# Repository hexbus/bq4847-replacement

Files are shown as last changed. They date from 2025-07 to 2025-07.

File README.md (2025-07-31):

# BQ4847 Replacement Module

**Drop-in replacement for the BQ4847Y DIP RTC chip using the BQ4802Y for 5V legacy systems.**  
Maintains full functionality with modern, readily available components.

---

## Table of Contents

- [Overview](#overview)
- [Photos](#photos)
  - [Assembled Replacement Module](#assembled-replacement-module)
  - [BQ4802Y Module (Modern)](#bq4802y-module-modern)
  - [BQ4847Y Chip (Original)](#bq4847y-chip-original)
- [Project Status](#project-status)
- [Bill of Materials (BOM)](#bill-of-materials-bom)
- [Installation Instructions](#installation-instructions)
  - [TI-99/4A IDE Card](#bq4852-ti99-ide-card)
- [License](#license)
- [Author](#author)

---

## Overview

Many legacy computer systems used the BQ4847 real-time clock (RTC) chip—an integrated lithium coin-cell battery-backed chip with a typical 10-year lifespan. Today, most of thee original chips are well beyond their intended service life.

This project provides a drop-in replacement using the newer BQ4802Y clock chip. It includes support for a replaceable 3V CR2032 battery via an XH 2-pin connector. Note that while the original BQ4847 supported an external 512K SRAM module, this project does **not** include that memory. However, the BQ4802Y can still manage external SRAM if present.

This design was created specifically for use in the [TI-99/4A IDE Card](http://www.mainbyte.com/ti99/ide_card/ide_card.html), which has a dedicated footprint for the BQ4847.

---

## Photos

### Assembled Replacement Module  
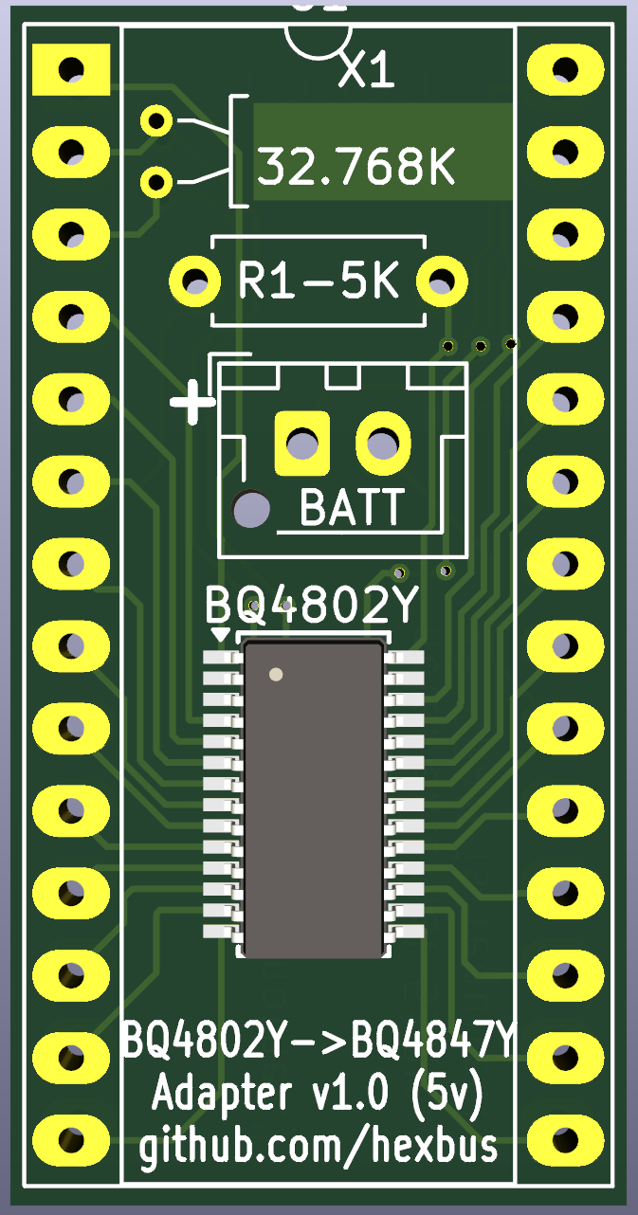
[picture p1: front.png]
Replacement Module


### BQ4802Y Module (Modern)  
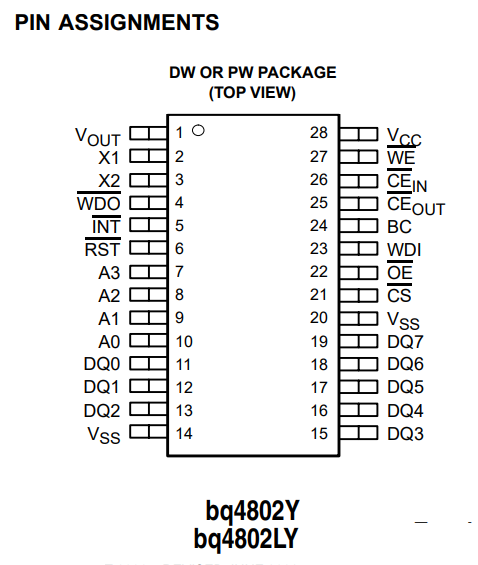
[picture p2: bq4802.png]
BQ4802Y


### BQ4847Y Chip (Original)  
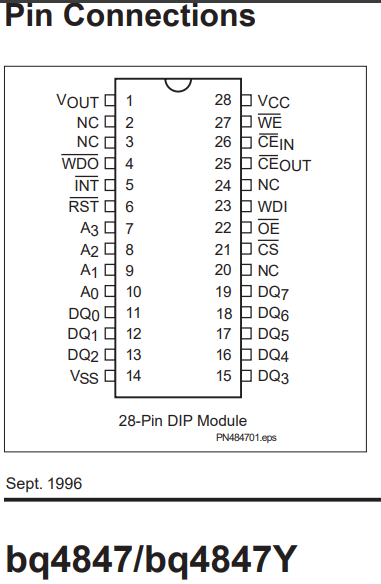
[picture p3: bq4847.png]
BQ4847Y


---

## Project Status

🛠️ **Current Status: Prototype phase**  
This design has not yet been tested in hardware. Boards are on order and manual builds are pending.

---

## Bill of Materials (BOM)

| Component | Description | Est. Cost (USD) | Source/Link |
|---|---|---|---|
| PCB | Found in `gerbers.zip` in this repo | — | — |
| BQ4802Y RTC chip | Main RTC IC | ~$6.25 | [Mouser](https://www.mouser.com/ProductDetail/Texas-Instruments/BQ4802YPW?qs=YxwvVplHM%2FnrYmh0JbPldA%3D%3D) |
| 32.768 kHz Crystal | Standard watch crystal for RTC - 8mm tall | $0.20–$0.40 | Mouser |
| 5K Resistor | Pull-up resistor - 1/4W 5% | ~$0.10 | Mouser |
| Round Pin Headers | For DIP socket compatibility | ~$0.50 | Various |
| XH 2 pin 2.54mm header | For hooking up 3V battery & holder (male/female) | $1.00/ea | [Example](https://www.amazon.com/JST-XH-2-54mm-Connector-Silicone-Cables/dp/B0D6KSMK1Q/) |
| Battery holder - CR2032  | Battery holder w/switch & CR2032 - Backup | $2.00/ea | [Example](https://www.amazon.com/Alinan-Button-Battery-Storage-Container/dp/B09KTVG1Y5) |

---

## Installation Instructions

### BQ4852 TI99 IDE Card

Many early TI-99/4A IDE cards were populated with the **BQ4852**, a combination real-time clock (RTC) and 512K SRAM chip with an internal, non-replaceable battery. At this point, most of these batteries are long dead.

These instructions assume you're replacing the BQ4852 with a modern alternative (the one from this repo) using the other supported clock header on the IDE card—the **BQ4802** in the **BQ4847-compatible socket**. Unlike the BQ4852, the BQ4802 (and most other supported options) do **not** include integrated SRAM. To maintain compatibility, the card’s [original designer](https://www.unige.ch/medecine/nouspikel/ti99/ide2.htm) included a footprint at **IC23** to add external 512K SRAM.

If you're installing a clock chip **without built-in SRAM**, you'll need to populate IC23 with a compatible SRAM chip. The following steps walk through the full replacement process.

---

1. **Remove the Original BQ4852**  
   Carefully remove the BQ4852 from **IC27** by pulling it straight up. This removes both the clock and built-in SRAM.

2. **Install External SRAM**  
   Populate **IC23** with a [512Kx8 SRAM chip](https://www.mouser.com/ProductDetail/727-CY2148ELL45ZSXIT).

3. **Install Required Capacitors**  
   Solder two [0805 0.1uf surface-mount capacitors](https://www.mouser.com/ProductDetail/KEMET/C0805C104M5RAC7210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):
   - **C23** — decoupling for the SRAM at IC23
   - **C25** — decoupling for the new clock chip at the BQ4847 socket

4. **Insert the BQ4802 Clock Chip Assembly**  
   Insert the BQ4802 Kit Assembly into the **BQ4847 socket**:
   - Align the dot on the chip with the notch in the silkscreen (facing **C25** and the top edge of the IDE card).
   - The crystal and resistor should be installed just above the chip.

5. **Attach and Secure the [Battery Holder](https://www.amazon.com/Alinan-Button-Battery-Storage-Container/dp/B09KTVG1Y5?th=1)**  
   - Connect a CR2032 battery holder to the 2-pin XH 2.54mm female header and insulate appropriately.
   - Ensure correct polarity (**+ on the left**, per the silkscreen).
   - Mount the battery holder securely nearby using double-sided tape.
   - Leave the **battery switch OFF** during initial testing.

6. **Set the IDE Card Switch**  
   - Set the rear **IDE switch** to the **OFF** position (usually the center setting).

7. **Power On the System**  
   - Power on your **Peripheral Expansion System (PEB)**.
   - Power on your **TI-99/4A** and wait for the Master Title Screen.
   - Flip the IDE card’s switch to **TI** (if using a TI-compatible configuration).

8. **Load the IDE DSR**  
   - Run `IDELOAD` to detect and initialize the IDE card’s DSR (Device Service Routine).
   - The best way to load the DSR is via the 64K cartridge image (loaded in a FinalGROM, FlashROM99, UberGROM, or Guidry 64K cartridge board).  This binary is located in the idedsr_v17.zip as of the writing of this readme, [on this page.](https://hexbus.com/ti99geek/Projects/idedsr/idedsr.html#idedsr)
    
9. **Test Battery Backup Functionality**  
   - If the DSR loads successfully:
     - Turn the **battery switch ON**.
     - Power down the system, then power it back up.
     - In BASIC, run `CALL IDEST` or `CALL IDETD` to verify the date and time were retained.

10. **Troubleshooting Tips**  
    - If the DSR does not load or the clock fails to retain time:
      - Recheck all IC placements and capacitor installations.
      - Use a multimeter to verify connectivity and power.
      - Confirm the DSR is still present by rerunning `IDELOAD`.
      - Make sure you have the current version of the IDE DSR, and follow the troubleshooting steps [here](https://hexbus.com/ti99geek/Projects/idedsr/idedsr.html#idedsr).
      - Seek help via community resources like the [TI-99/4A Forum on AtariAge](https://forums.atariage.com/forum/164-ti-994a-computers/).

---

## License

This project is open hardware. You are free to use, modify, and distribute it, ideally with attribution. Please see the license file in this repo.

---

## Author

Designed by [hexbus](https://github.com/hexbus).

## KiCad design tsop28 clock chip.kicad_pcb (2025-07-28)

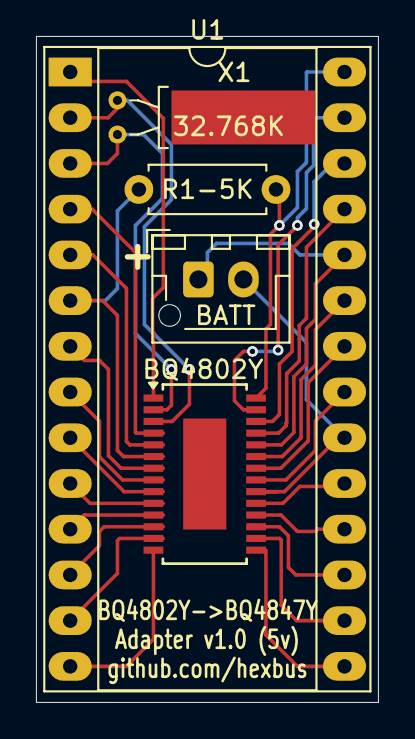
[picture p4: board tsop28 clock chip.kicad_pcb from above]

Board: 2 copper layers, 19.0 x 37.0 mm, 5 parts (0 on the bottom side), 28 nets.

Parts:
32.768K: 5K; R_Axial_DIN0207_L6.3mm_D2.5mm_P7.62mm_Horizontal
BATT: JST_XH_B2B-XH-AM_1x02_P2.50mm_Vertical
BQ4802Y: TSSOP-28-1EP_4.4x9.7mm_P0.65mm
U1: DIP-28_W15.24mm_Socket_LongPads
X1: 32.768K; Crystal_C38-LF_D3.0mm_L8.0mm_Horizontal_1EP_style1

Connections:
1: BQ4802Y.1, U1.1
2: BQ4802Y.3, U1.2, X1.2
3: BQ4802Y.2, U1.3, X1.1
4: BQ4802Y.4, U1.4
5: BQ4802Y.5, U1.5
6: 32.768K.1, BQ4802Y.6, U1.6
7: BQ4802Y.7, U1.7
8: BQ4802Y.8, U1.8
9: BQ4802Y.9, U1.9
10: BQ4802Y.10, U1.10
11: BQ4802Y.11, U1.11
12: BQ4802Y.12, U1.12
13: BQ4802Y.13, U1.13
14: BQ4802Y.14, U1.14
15: BQ4802Y.15, U1.15
16: BQ4802Y.16, U1.16
17: BQ4802Y.17, U1.17
18: BQ4802Y.18, U1.18
19: BQ4802Y.19, U1.19
20: BATT.2, BQ4802Y.20, U1.20
21: BQ4802Y.21, U1.21
22: BQ4802Y.22, U1.22
23: BQ4802Y.23, U1.23
24: BATT.1, BQ4802Y.24, U1.24
25: BQ4802Y.25, U1.25
26: BQ4802Y.26, U1.26
27: BQ4802Y.27, U1.27
28: 32.768K.2, BQ4802Y.28, U1.28
